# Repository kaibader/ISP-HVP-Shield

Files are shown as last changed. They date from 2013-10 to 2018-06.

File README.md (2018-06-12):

# ISP-HVP-Shield

Arduino ISP and HVSP/HVPP Shield for ATtiny Microcontoller

## Preface

**This repository is discontinued and only provided for others to further work
with its content.**

Eagle CAD version 7 was used to create the schematic and board files. The latest
version I've tested was Eagle CAD v7.7. I do not support the price and product
policy of Autodesk and therefore have moved from Eagle CAD to the free and open
source KiCad. I can only recommend you to do the same.

## Version 1.0

This is the original version of the Arduino ISP shield which not only has been
successfully tested but also copied/created by various other users.

**If you are unsure which version to use for further experiments stick to this
one.**

## Version 1.1

This was a slightly improved version of the original ATtiny ISP Shield.
This version was *never produced and never tested* as real hardware.

## Version 2.0

This was an experimental version which not only should allow the programming
of ATtiny microcontollers but also erase their fuses (via high voltage
programming).

The TopoR autorouter was used to route the v2.0 board which then was used to
generate the Gerber files. I've added an ripped-up version of the board for
compatibility reasons.

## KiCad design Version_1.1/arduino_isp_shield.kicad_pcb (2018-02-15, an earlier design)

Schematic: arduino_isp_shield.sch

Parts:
C1, C2: 0.1uF; C_Disc_D3.8mm_W2.6mm_P2.50mm
C4: 10uF; CP_Radial_D5.0mm_P2.50mm
J1: ISP; PinHeader_2x03_P2.54mm_Vertical
J2: Conn_01x08; PinHeader_1x08_P2.54mm_Vertical
J3: Conn_01x10; PinHeader_1x10_P2.54mm_Vertical
U1: ATTINY13/15/25/45/85; DIP-8_W7.62mm
U2: ATTINY24/44/84; DIP-14_W7.62mm
U3: ATTINY2313/4313; DIP-20_W7.62mm

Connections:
+5V: C1.1, C2.1, J1.2, J2.5, U1.8 (VCC), U2.1 (VCC), U3.20
/MISO: J1.1, J3.6, U1.6 (PB1(MISO/DO/AIN1/OC0B/OC1A/PCINT1)), U2.8 ((PCINT5/DO/MISO/OC1B/ADC5)PA5), U3.18
/MOSI: J1.4, J3.7, U1.5 (PB0(MOSI/DI/SDA/AIN0/OC0A/OC1A/AREF/PCI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), U2.7 ((PCINT6/SDA/DI/MOSI/OC1A/ADC6)PA6), U3.17
/SCK: J1.3, J3.5, U1.7 (PB2(SCK/USCK/SCL/T0/INT0/ADC1/PCINT2)), U2.9 ((PCINT4/USCK/SCL/T1/ADC4)PA4), U3.19
/~RESET: J1.5, J3.8, U1.1 (PB5(~RESET~/dW/ADC0/PCINT5)), U2.4 ((PCINT11/dW/~RESET~)PB3), U3.1
GND: C1.2, C2.2, C4.2, J1.6, J2.6, J2.7, J3.4, U1.4 (GND), U2.14 (GND), U3.10
unnamed: C4.1, J2.3

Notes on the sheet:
Decoupling Capacitors (optional)
Optional/External ISP

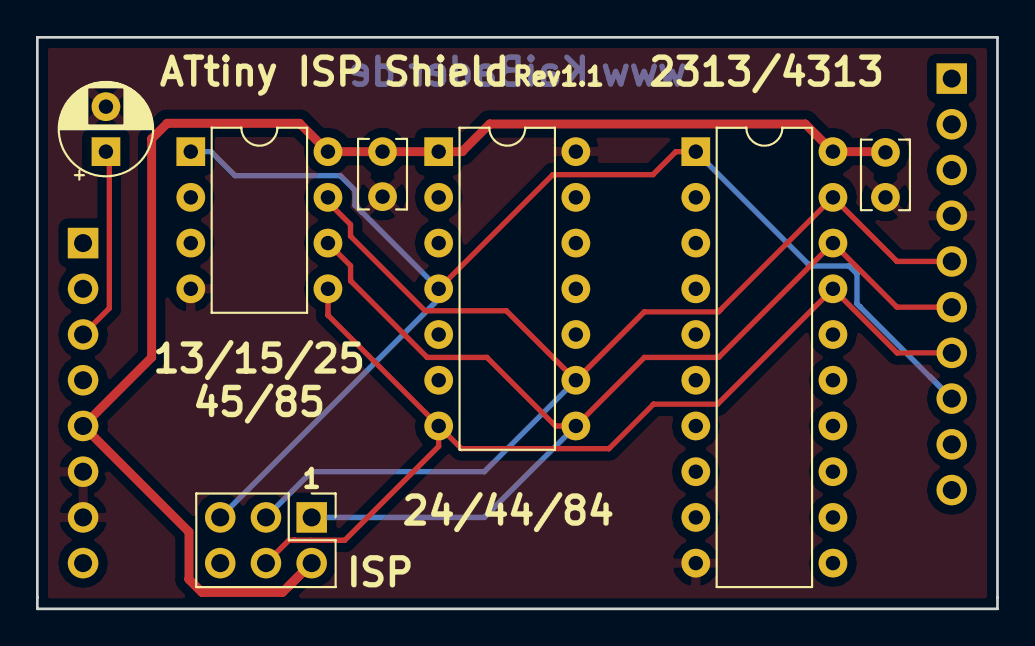
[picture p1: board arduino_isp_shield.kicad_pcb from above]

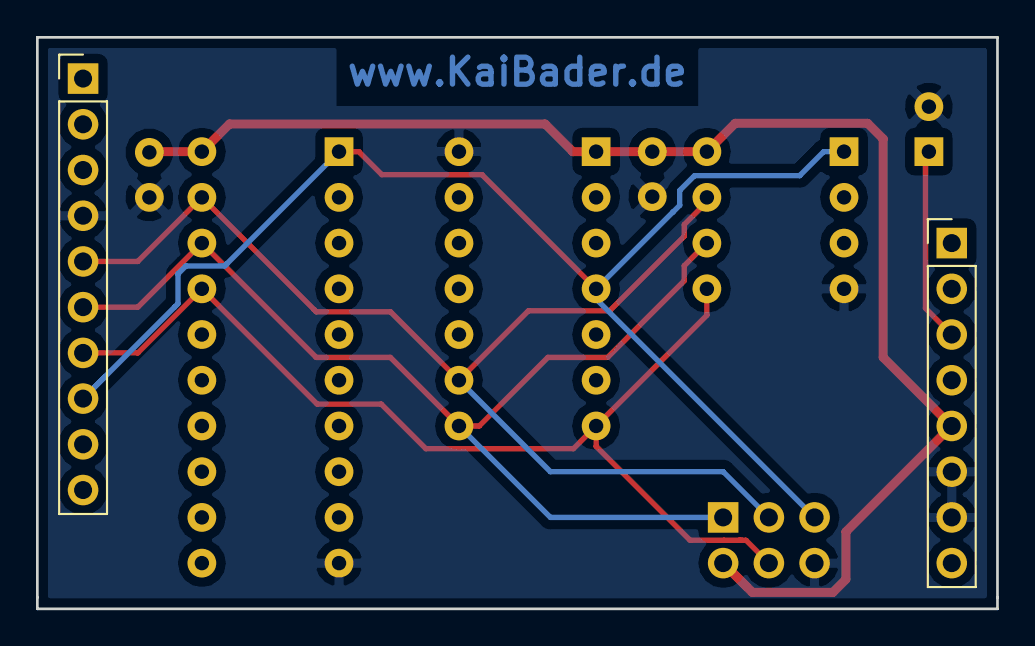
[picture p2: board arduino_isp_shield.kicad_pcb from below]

Board: 2 copper layers, 53.3 x 31.8 mm, 9 parts (2 on the bottom side), 7 nets.

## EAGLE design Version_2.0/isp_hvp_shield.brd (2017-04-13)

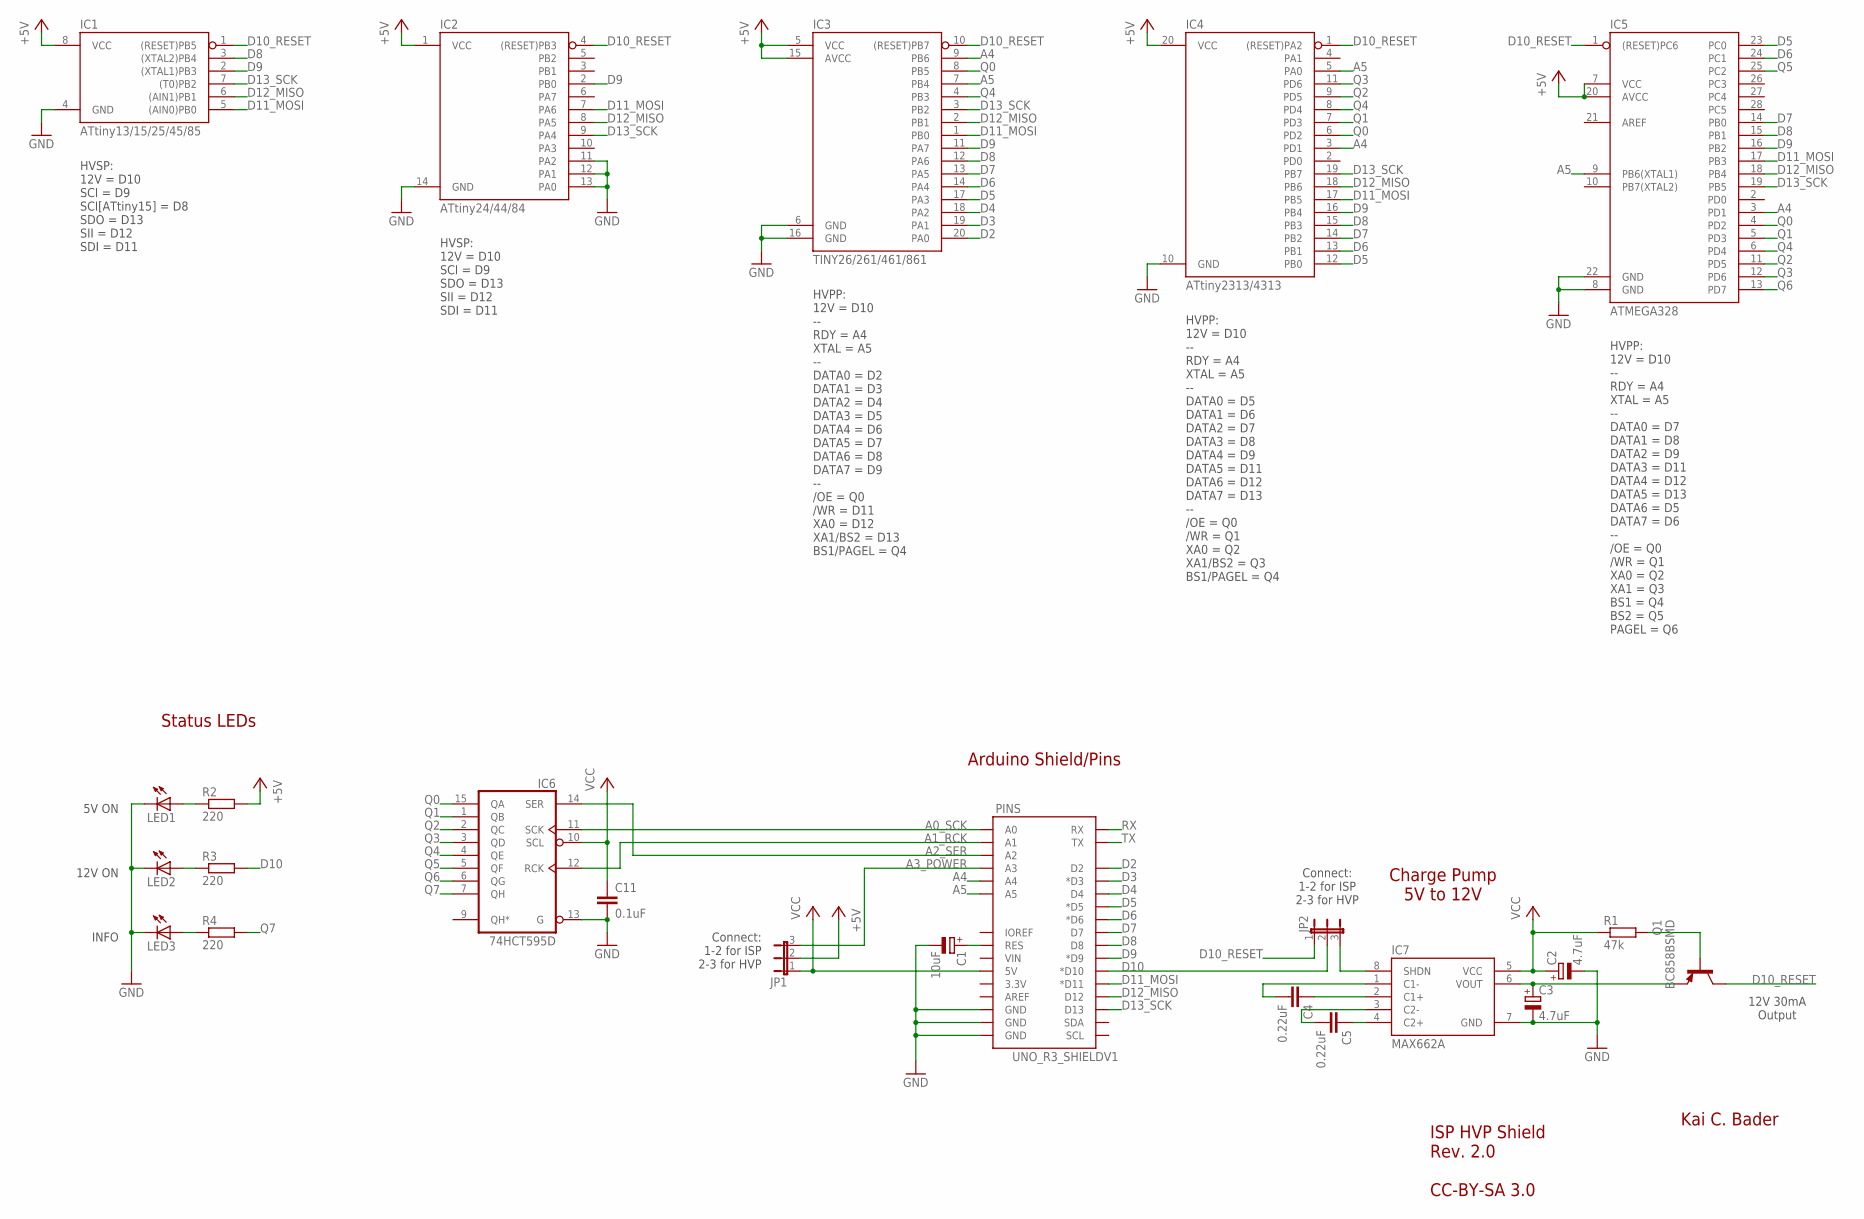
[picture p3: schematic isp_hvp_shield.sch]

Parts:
C1: 10uF; E2-5
C2, C3: 4.7uF; E2-5
C4, C5: 0.22uF; C0805
C11: 0.1uF; C0805
IC1: ATtiny13/15/25/45/85; DIL08
IC2: ATtiny24/44/84; DIL14
IC3: TINY26/261/461/861; DIL20
IC4: ATtiny2313/4313; DIL20
IC5: ATMEGA328; DIL28
IC6: 74HCT595D; SO16
IC7: MAX662A; SO08
JP1, JP2: JP2E; JP2
LED1, LED2, LED3: LEDCHIPLED_0805; CHIPLED_0805
PINS: UNO_R3_SHIELDV1; UNO_R3_SHIELD
Q1: BC858BSMD; SOT23-BEC
R1: 47k; R0805
R2, R3, R4: 220; R0805

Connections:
220: LED2.A, R3.1
+5V: IC1.8 (VCC), IC2.1 (VCC), IC3.5 (VCC), IC3.15 (AVCC), IC4.20 (VCC), IC5.7 (VCC), IC5.20 (AVCC), JP1.2, R2.2
A0_SCK: IC6.11 (SCK), PINS.A0
A1_RCK: IC6.12 (RCK), PINS.A1
A2_SER: IC6.14 (SER), PINS.A2
A3_POWER: JP1.3, PINS.A3
A4: IC3.9 (PB6), IC4.3 (PD1), IC5.3 (PD1), PINS.A4
A5: IC3.7 (PB4), IC4.5 (PA0), IC5.9 (PB6(XTAL1)), PINS.A5
AREF: IC5.21 (AREF)
D2: IC3.20 (PA0), PINS.D2
D3: IC3.19 (PA1), PINS.D3 (*D3)
D4: IC3.18 (PA2), PINS.D4
D5: IC3.17 (PA3), IC4.12 (PB0), IC5.23 (PC0), PINS.D5 (*D5)
D6: IC3.14 (PA4), IC4.13 (PB1), IC5.24 (PC1), PINS.D6 (*D6)
D7: IC3.13 (PA5), IC4.14 (PB2), IC5.14 (PB0), PINS.D7
D8: IC1.3 ((XTAL2)PB4), IC3.12 (PA6), IC4.15 (PB3), IC5.15 (PB1), PINS.D8
D9: IC1.2 ((XTAL1)PB3), IC2.2 (PB0), IC3.11 (PA7), IC4.16 (PB4), IC5.16 (PB2), PINS.D9 (*D9)
D10: JP2.2, PINS.D10 (*D10), R3.2
D10_RESET: IC1.1 ((RESET)PB5), IC2.4 ((RESET)PB3), IC3.10 ((RESET)PB7), IC4.1 ((RESET)PA2), IC5.1 ((RESET)PC6), JP2.1, Q1.C
D11_MOSI: IC1.5 ((AIN0)PB0), IC2.7 (PA6), IC3.1 (PB0), IC4.17 (PB5), IC5.17 (PB3), PINS.D11 (*D11)
D12_MISO: IC1.6 ((AIN1)PB1), IC2.8 (PA5), IC3.2 (PB1), IC4.18 (PB6), IC5.18 (PB4), PINS.D12
D13_SCK: IC1.7 ((T0)PB2), IC2.9 (PA4), IC3.3 (PB2), IC4.19 (PB7), IC5.19 (PB5), PINS.D13
GND: C1.-, C2.-, C3.-, C11.2, IC1.4 (GND), IC2.11 (PA2), IC2.12 (PA1), IC2.13 (PA0), IC2.14 (GND), IC3.6 (GND), IC3.16 (GND), IC4.10 (GND), IC5.8 (GND), IC5.22 (GND), IC6.8 (GND), IC6.13 (G), IC7.7 (GND), LED1.C, LED2.C, LED3.C, PINS.GND@0 (GND), PINS.GND@1 (GND), PINS.GND@2 (GND)
unnamed: IC7.8 (SHDN), JP2.3
unnamed: C1.+, PINS.RES
unnamed: Q1.B, R1.2
unnamed: C5.1, IC7.4 (C2+)
unnamed: C5.2, IC7.3 (C2-)
unnamed: C4.1, IC7.2 (C1+)
unnamed: C4.2, IC7.1 (C1-)
unnamed: LED1.A, R2.1
unnamed: LED3.A, R4.1
Q0: IC3.8 (PB5), IC4.6 (PD2), IC5.4 (PD2), IC6.15 (QA)
Q1: IC4.7 (PD3), IC5.5 (PD3), IC6.1 (QB)
Q2: IC4.9 (PD5), IC5.11 (PD5), IC6.2 (QC)
Q3: IC4.11 (PD6), IC5.12 (PD6), IC6.3 (QD)
Q4: IC3.4 (PB3), IC4.8 (PD4), IC5.6 (PD4), IC6.4 (QE)
Q5: IC5.25 (PC2), IC6.5 (QF)
Q6: IC5.13 (PD7), IC6.6 (QG)
Q7: IC6.7 (QH), R4.2
RX: PINS.RX
TX: PINS.TX
VCC: C2.+, C11.1, IC6.10 (SCL), IC6.16 (VCC), IC7.5 (VCC), JP1.1, PINS.5V, R1.1
VOUT: C3.+, IC7.6 (VOUT), Q1.E

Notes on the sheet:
Kai C. Bader
ISP HVP Shield Rev. 2.0 CC-BY-SA 3.0
Charge Pump 5V to 12V
Arduino Shield/Pins
HVSP: 12V = D10 SCI = D9 SCI[ATtiny15] = D8 SDO = D13 SII = D12 SDI = D11
HVSP: 12V = D10 SCI = D9 SDO = D13 SII = D12 SDI = D11
HVPP: 12V = D10 -- RDY = A4 XTAL = A5 -- DATA0 = D5 DATA1 = D6 DATA2 = D7 DATA3 = D8 DATA4 = D9 DATA5 = D11 DATA6 = D12 DATA7 = D13 -- /OE = Q0 /WR = Q1 XA0 = Q2 XA1/BS2 = Q3 BS1/PAGEL = Q4
Connect: 1-2 for ISP 2-3 for HVP
HVPP: 12V = D10 -- RDY = A4 XTAL = A5 -- DATA0 = D2 DATA1 = D3 DATA2 = D4 DATA3 = D5 DATA4 = D6 DATA5 = D7 DATA6 = D8 DATA7 = D9 -- /OE = Q0 /WR = D11 XA0 = D12 XA1/BS2 = D13 BS1/PAGEL = Q4
HVPP: 12V = D10 -- RDY = A4 XTAL = A5 -- DATA0 = D7 DATA1 = D8 DATA2 = D9 DATA3 = D11 DATA4 = D12 DATA5 = D13 DATA6 = D5 DATA7 = D6 -- /OE = Q0 /WR = Q1 XA0 = Q2 XA1 = Q3 BS1 = Q4 BS2 = Q5 PAGEL = Q6
12V 30mA Output
Status LEDs
5V ON
12V ON
INFO

Board: 2 copper layers, 26 parts (0 on the bottom side), 41 nets, no tracks yet.

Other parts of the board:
U$1: OSHW-LOGO-S
U$3: KAI-LOGO-M

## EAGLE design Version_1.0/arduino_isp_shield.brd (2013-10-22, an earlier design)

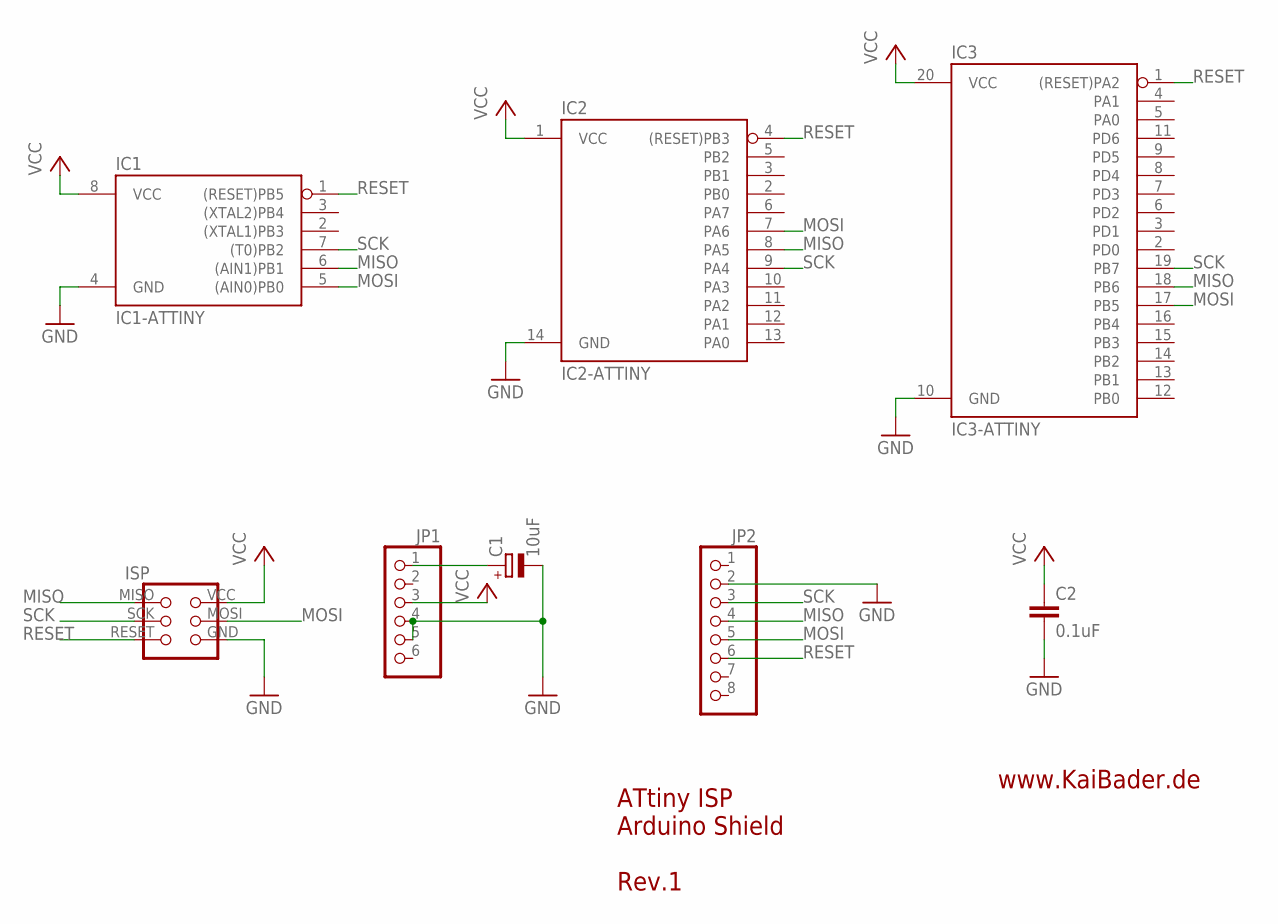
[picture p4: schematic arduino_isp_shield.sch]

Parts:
C1: 10uF; E1,8-4
C2: 0.1uF; C050-025X075
IC1: IC1-ATTINY; DIL08
IC2: IC2-ATTINY; DIL14
IC3: IC3-ATTINY; DIL20
ISP: AVR-ISP
JP1: PINHD-1X6; 1X06
JP2: PINHD-1X8; 1X08

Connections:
GND: C1.-, C2.2, IC1.4 (GND), IC2.14 (GND), IC3.10 (GND), ISP.GND, JP1.4, JP1.5, JP2.2
MISO: IC1.6 ((AIN1)PB1), IC2.8 (PA5), IC3.18 (PB6), ISP.MISO, JP2.4
MOSI: IC1.5 ((AIN0)PB0), IC2.7 (PA6), IC3.17 (PB5), ISP.MOSI, JP2.5
unnamed: C1.+, JP1.1
RESET: IC1.1 ((RESET)PB5), IC2.4 ((RESET)PB3), IC3.1 ((RESET)PA2), ISP.RESET, JP2.6
SCK: IC1.7 ((T0)PB2), IC2.9 (PA4), IC3.19 (PB7), ISP.SCK, JP2.3
VCC: C2.1, IC1.8 (VCC), IC2.1 (VCC), IC3.20 (VCC), ISP.VCC, JP1.3

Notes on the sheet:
www.KaiBader.de
ATtiny ISP Arduino Shield Rev.1

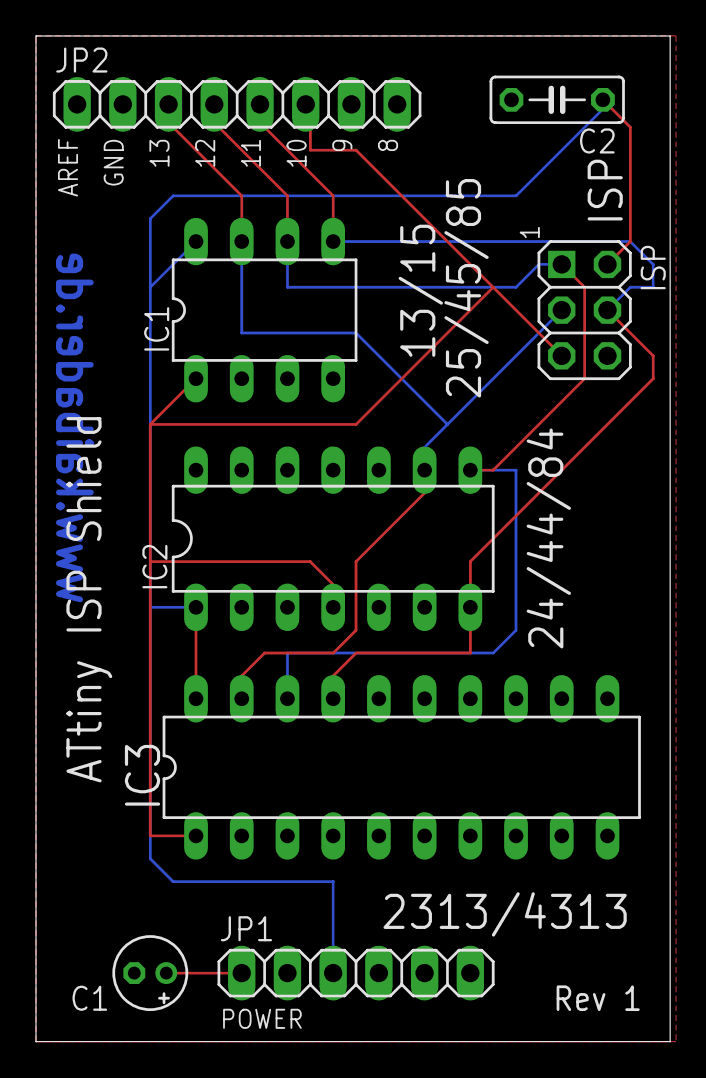
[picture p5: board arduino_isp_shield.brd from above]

Board: 2 copper layers, 35.2 x 55.9 mm, 8 parts (0 on the bottom side), 7 nets.

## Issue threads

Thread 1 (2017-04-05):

Eagle gives error

u271D, 2017-04-05:
Eagle 8 gives the same error on both the board and schematic files

Error:

line 8, column 16: This is not an EAGLE file.

kaibader, 2017-04-13:
I've updated the board and schematic files with the latest version of Eagle CAD (version 7.7).
I'm sorry but I neither use nor support version 8 of Eagle CAD.

Closed 2017-04-13.

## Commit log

2013-10-22 Initial commit (ignore list). This is a repository of my Eagle CAD files.
2013-10-22 Added new files. May need to be cleaned up later...
    [arduino_isp_shield.GBL, arduino_isp_shield.GBO, arduino_isp_shield.GBP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]
2015-03-19 New design. Started to add HVSP/HVPP features.
    [arduino_isp_shield.GBL, arduino_isp_shield.GBO, arduino_isp_shield.GBP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]
2015-03-20 Added test board 'optimized' with topor.
    [isp_hvp_shield_topor_01.brd, isp_hvp_shield_topor_02.brd]
2015-03-21 Added Gerber files.
    [isp_hvp_shield.GBL, isp_hvp_shield.GBO, isp_hvp_shield.GBP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]
2015-03-21 Sent Gerber files to fab house...
    [isp_hvp_shield_topor.brd, isp_hvp_shield_topor_01.brd]
2015-04-19 A little bit of housecleaning...
    [arduino_isp_shield.GBL, arduino_isp_shield.GBO, arduino_isp_shield.GBP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]
2015-04-25 More cleaning...
    [arduino_isp_shield.GBL, arduino_isp_shield.GBO, arduino_isp_shield.GBP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]
2017-04-13 Fixed the forward<->backward compatibility.
    - Ripped up the board file to fix the schematic board compatibility.
    - Moved the TopoR (auto)routed board to a different location.
    [isp_hvp_shield.brd, isp_hvp_shield.sch, isp_hvp_shield_topor.brd]
2018-02-14 New Revision 1.1 Board designed with KiCad
    This board is identical to Revision 1.0 besides two instead of one
    decoupling capacitor and a new layout.
    [arduino_isp_shield.brd, arduino_isp_shield.kicad_pcb, arduino_isp_shield.sch]
2018-02-15 Minor adaptions: improved the alignment of some traces.
    [arduino_isp_shield.kicad_pcb]
2018-02-15 Minor fix due to DRC warning
    [arduino_isp_shield.kicad_pcb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]
2018-02-15 Renamed the Gerber files
    [arduino_isp_shield.gbl, arduino_isp_shield.gbs, arduino_isp_shield.gtl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]
2018-02-15 Minor Silk Screen Fix
    [arduino_isp_shield.gto]
2018-06-12 Renamed 'Revision_*' into 'Version_*'... avoids confusion.
    [arduino_isp_shield.GBL, arduino_isp_shield.GBO, arduino_isp_shield.GBP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]

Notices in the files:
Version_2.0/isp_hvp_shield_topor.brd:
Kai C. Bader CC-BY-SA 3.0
